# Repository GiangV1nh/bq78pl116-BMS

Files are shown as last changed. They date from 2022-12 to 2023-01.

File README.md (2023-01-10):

# Thông số kỹ thuật
- Số tế bào: 3
- Loại tế bào: Li-Ion
- Điện áp tế bào: 2.75V - 4.5V
- Điện áp pin: 8.25V - 12.6V
- Dòng nạp tối đa: 10A
- Dòng xả tối đa: 11.2A
- Cân bằng chủ động
- Dòng cân bằng: 143mA
- Giao tiếp: SMBus

Mặt trên|Mặt dưới
:-:|:-:
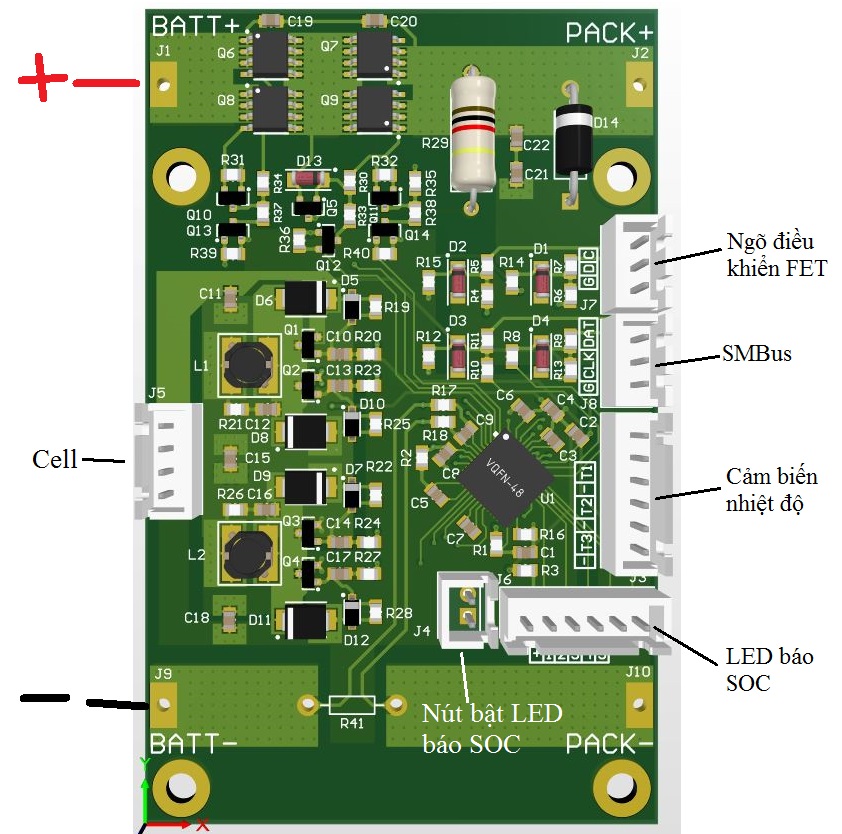
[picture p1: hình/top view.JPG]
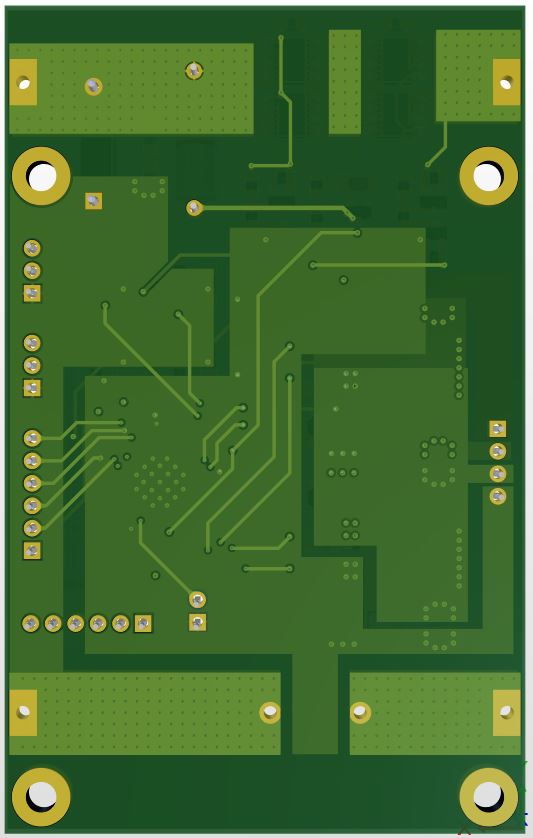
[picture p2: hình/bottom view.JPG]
|

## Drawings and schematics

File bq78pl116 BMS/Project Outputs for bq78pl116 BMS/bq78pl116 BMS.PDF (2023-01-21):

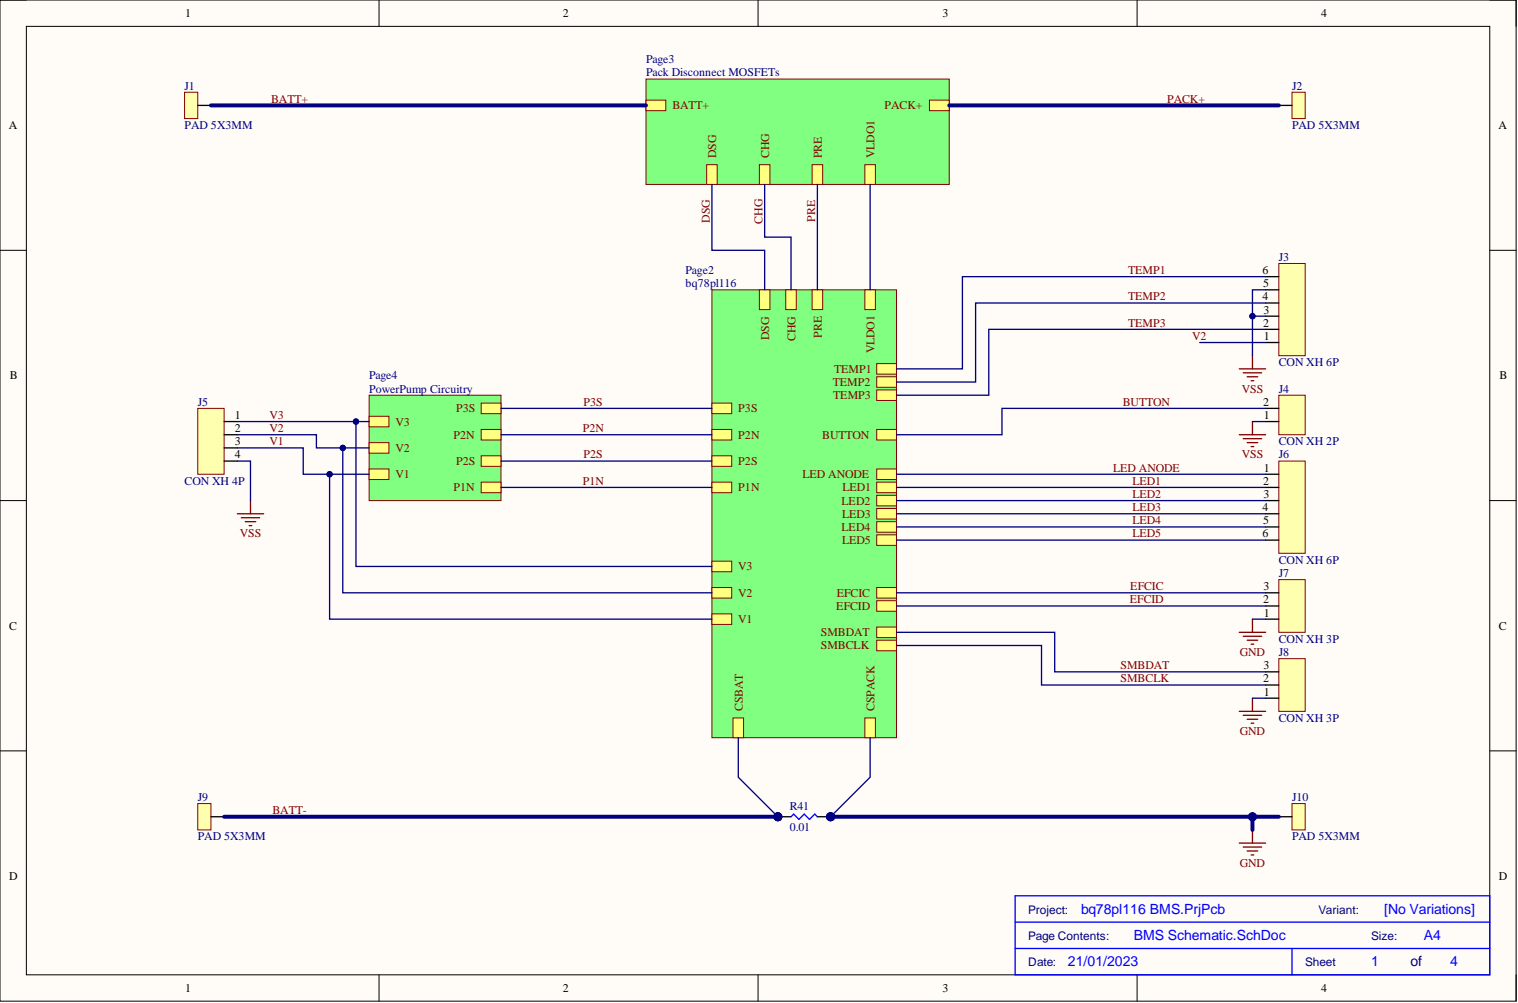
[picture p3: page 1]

T EMP3

V 2 | | P2 N
V 1

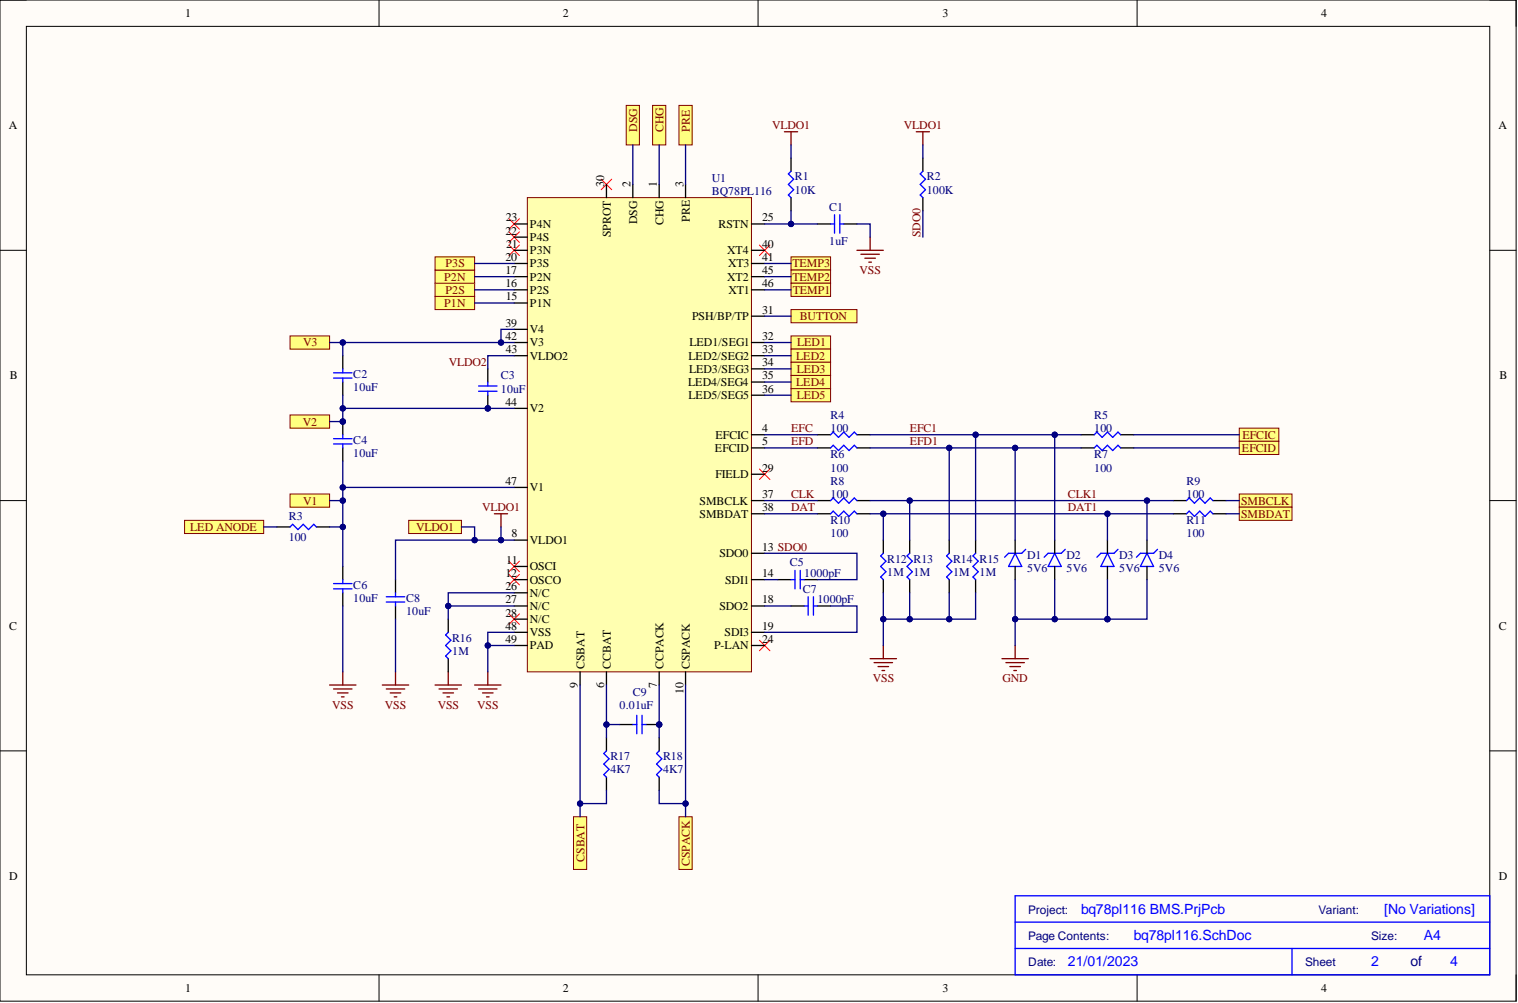
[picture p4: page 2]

P2N | TEMP2
P2S | TEMP1

OSCI 11

VSS 48

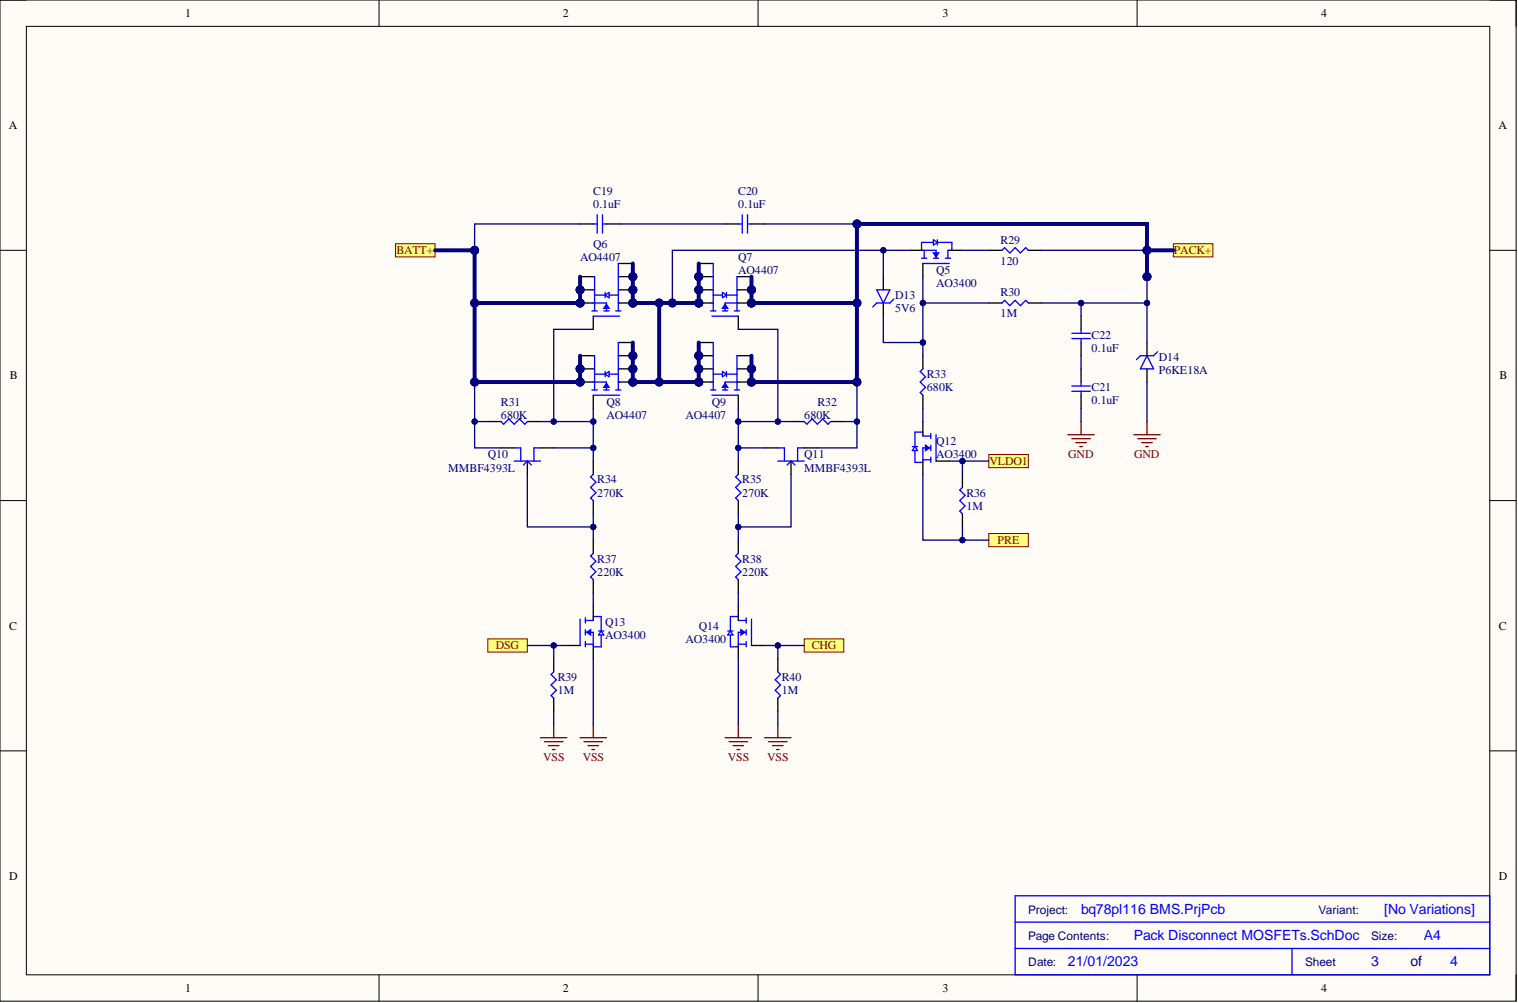
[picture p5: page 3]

D 1
5 V

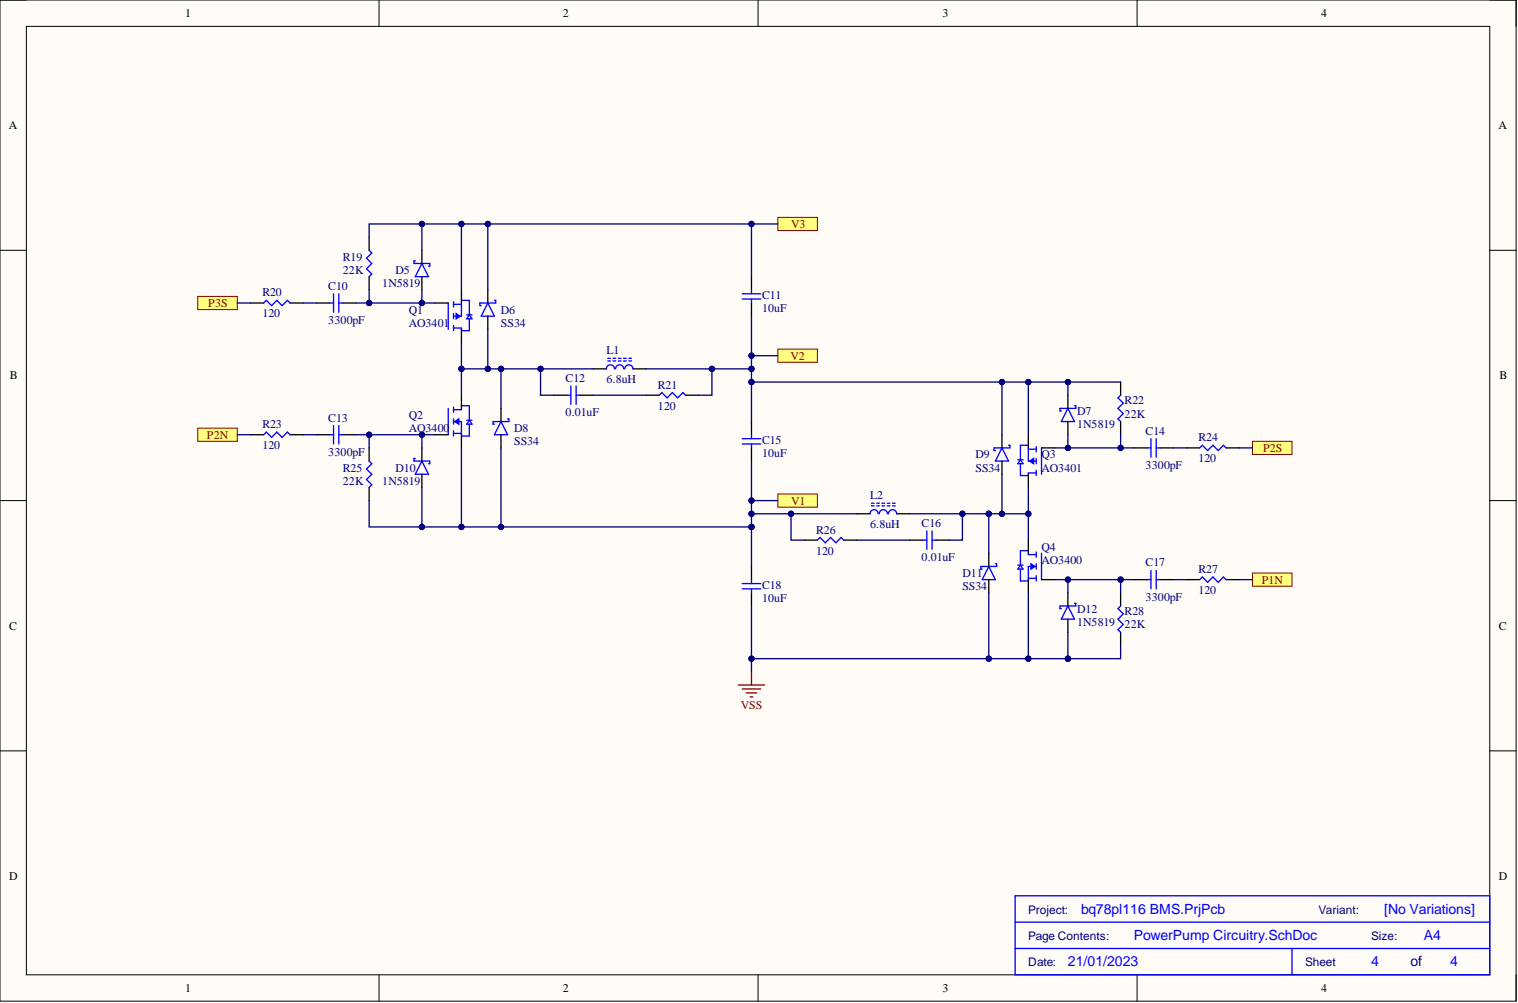
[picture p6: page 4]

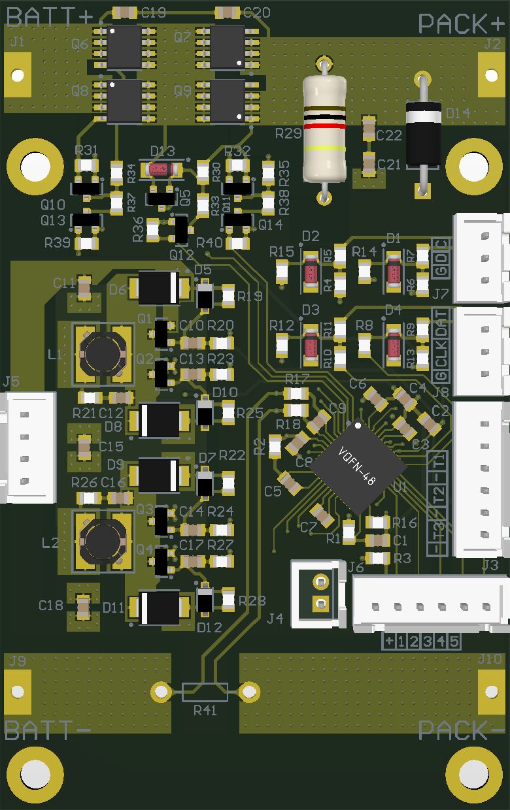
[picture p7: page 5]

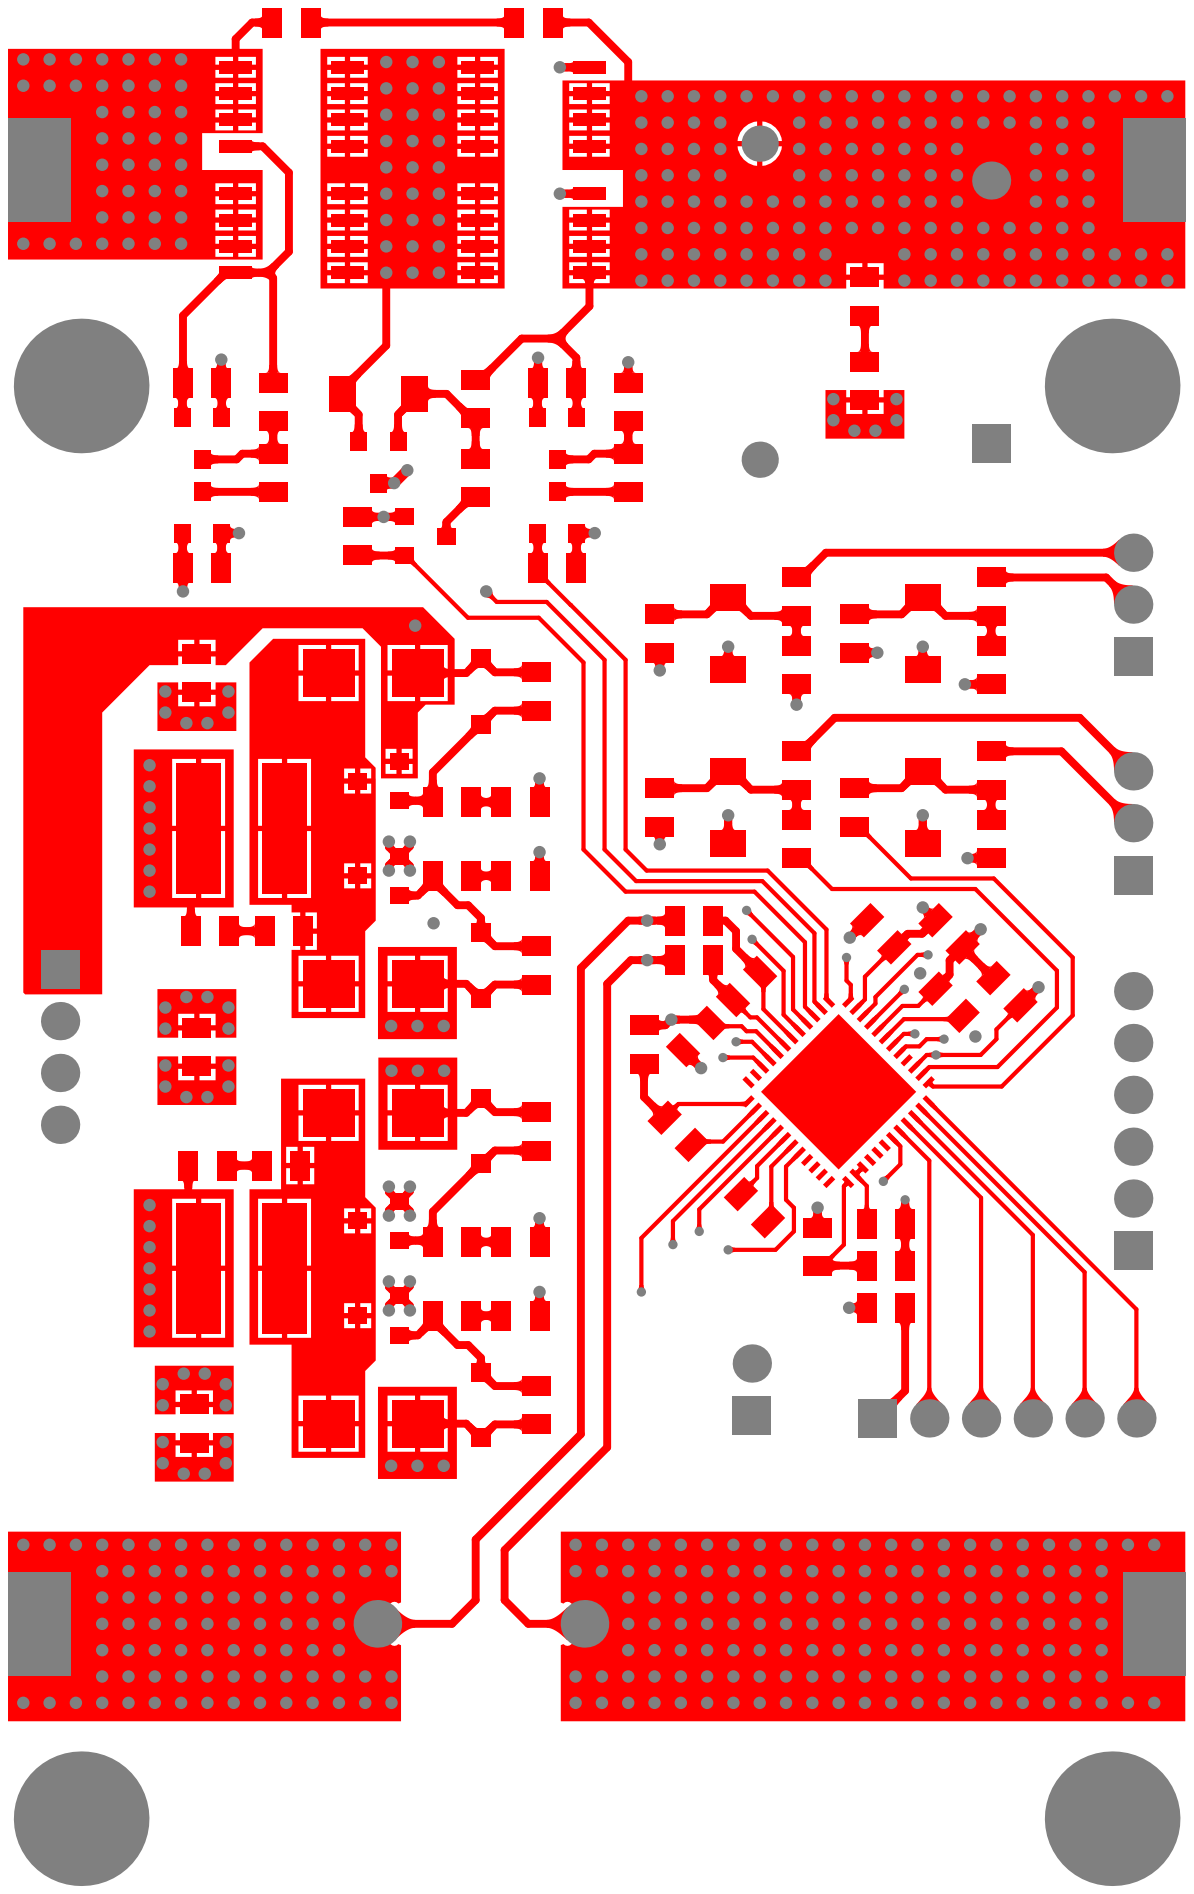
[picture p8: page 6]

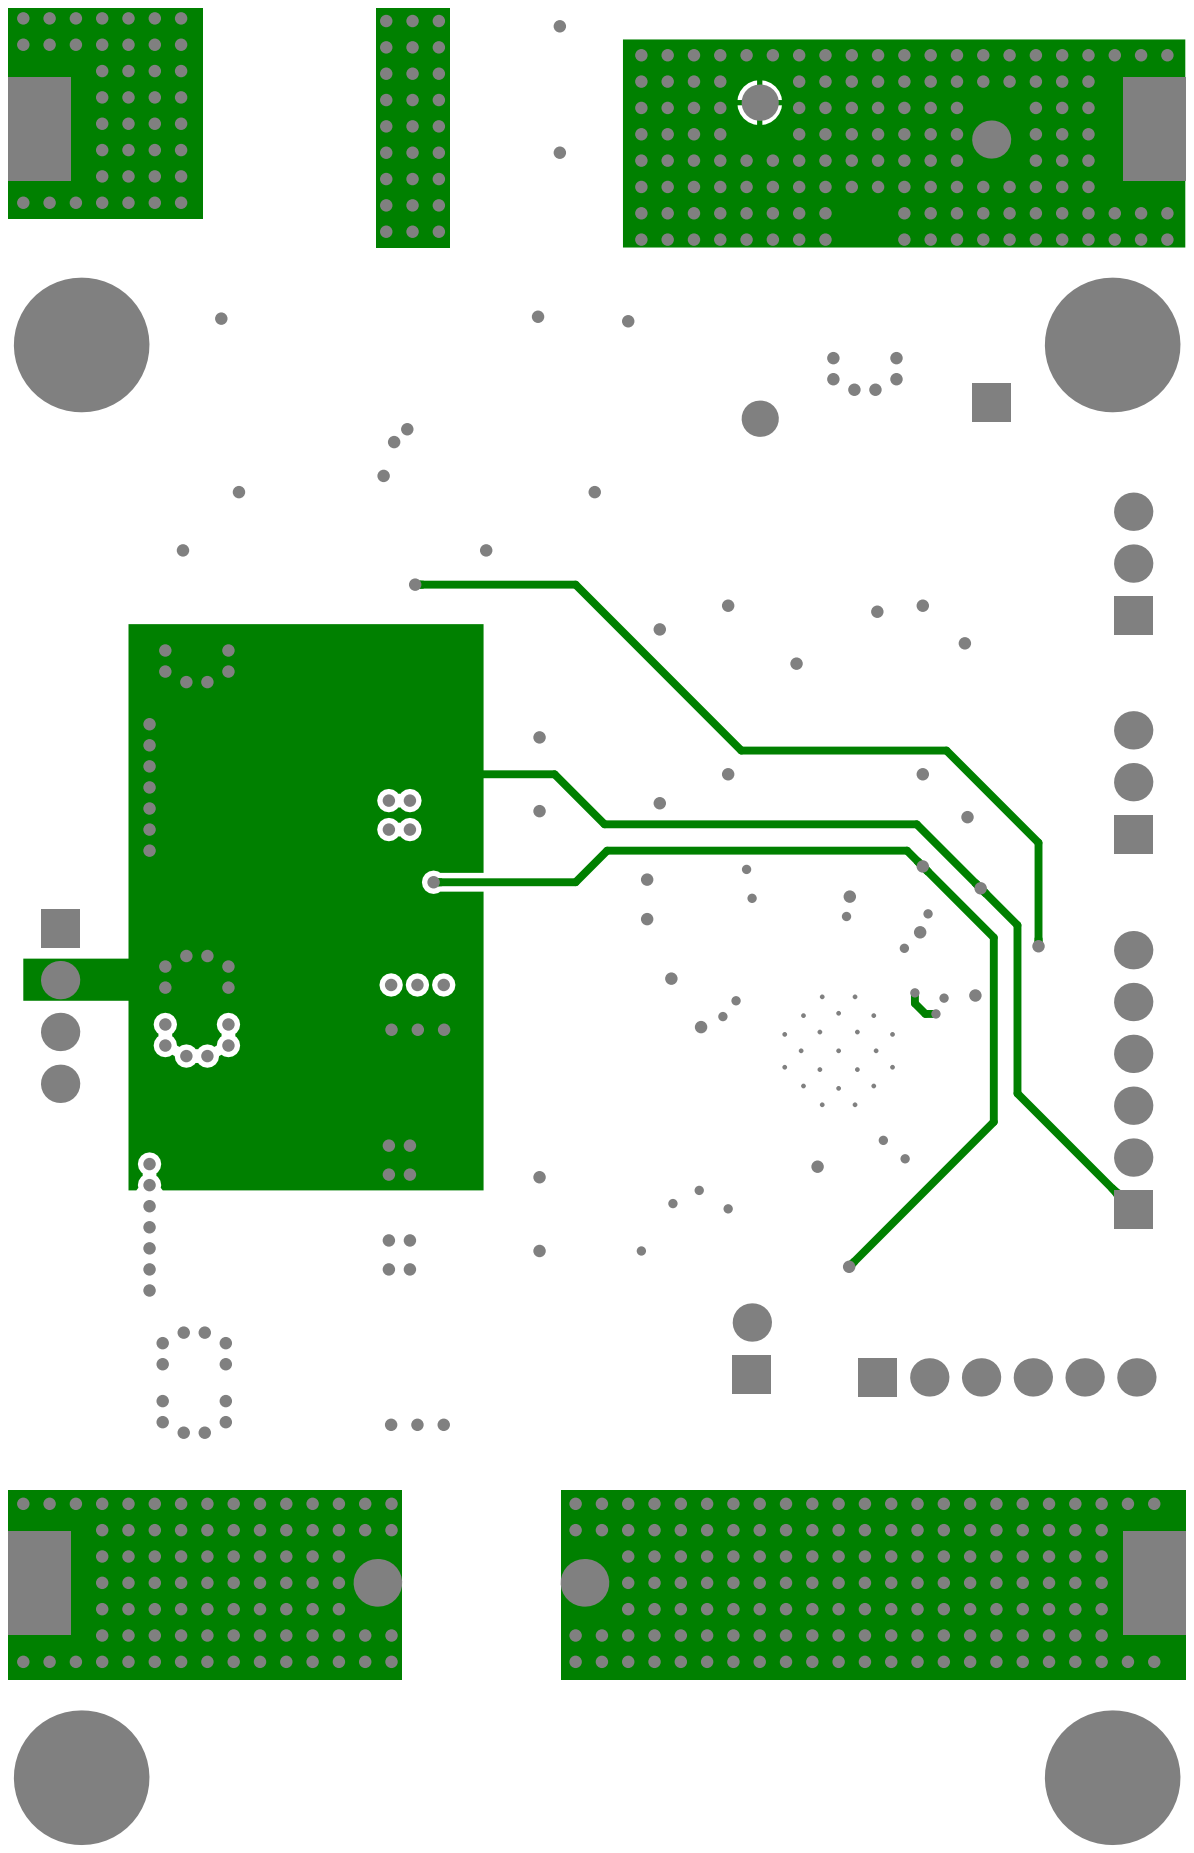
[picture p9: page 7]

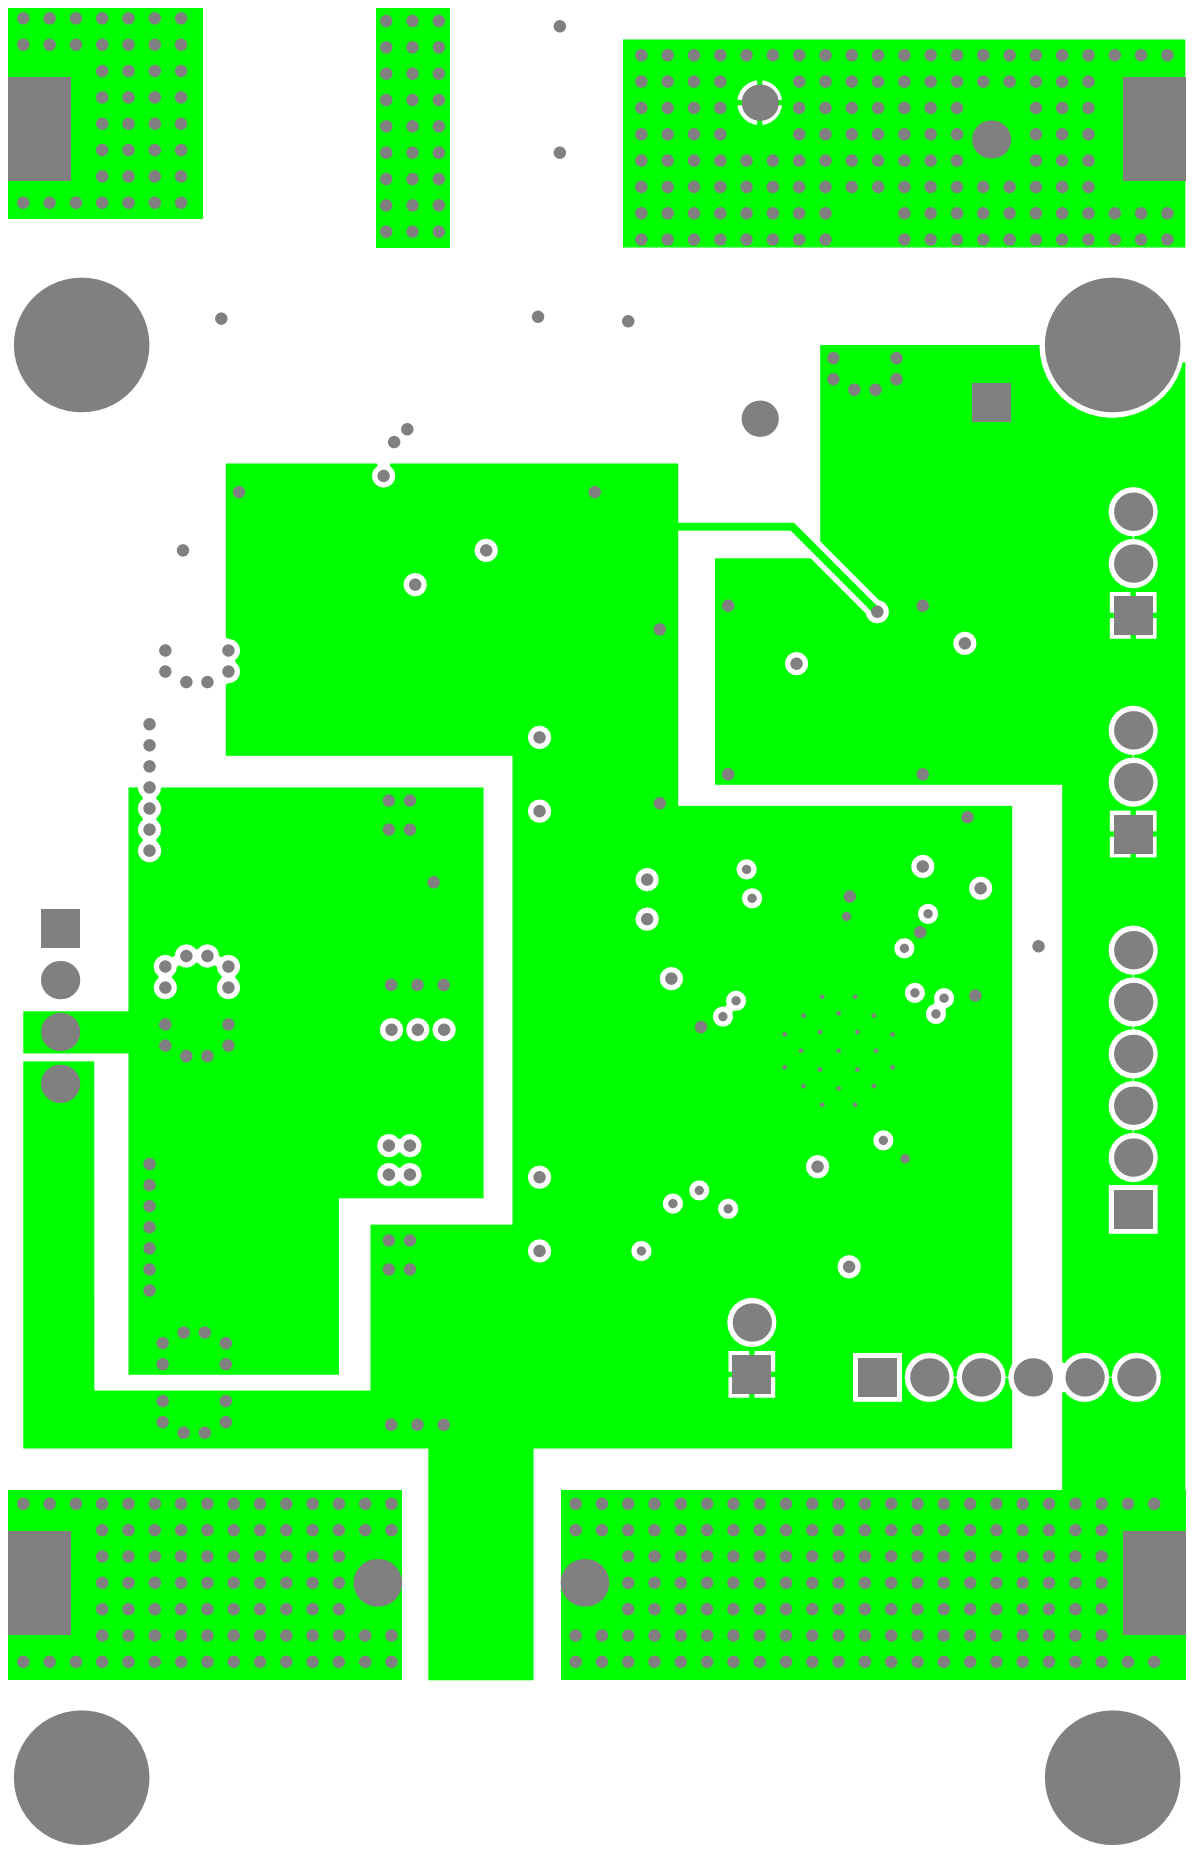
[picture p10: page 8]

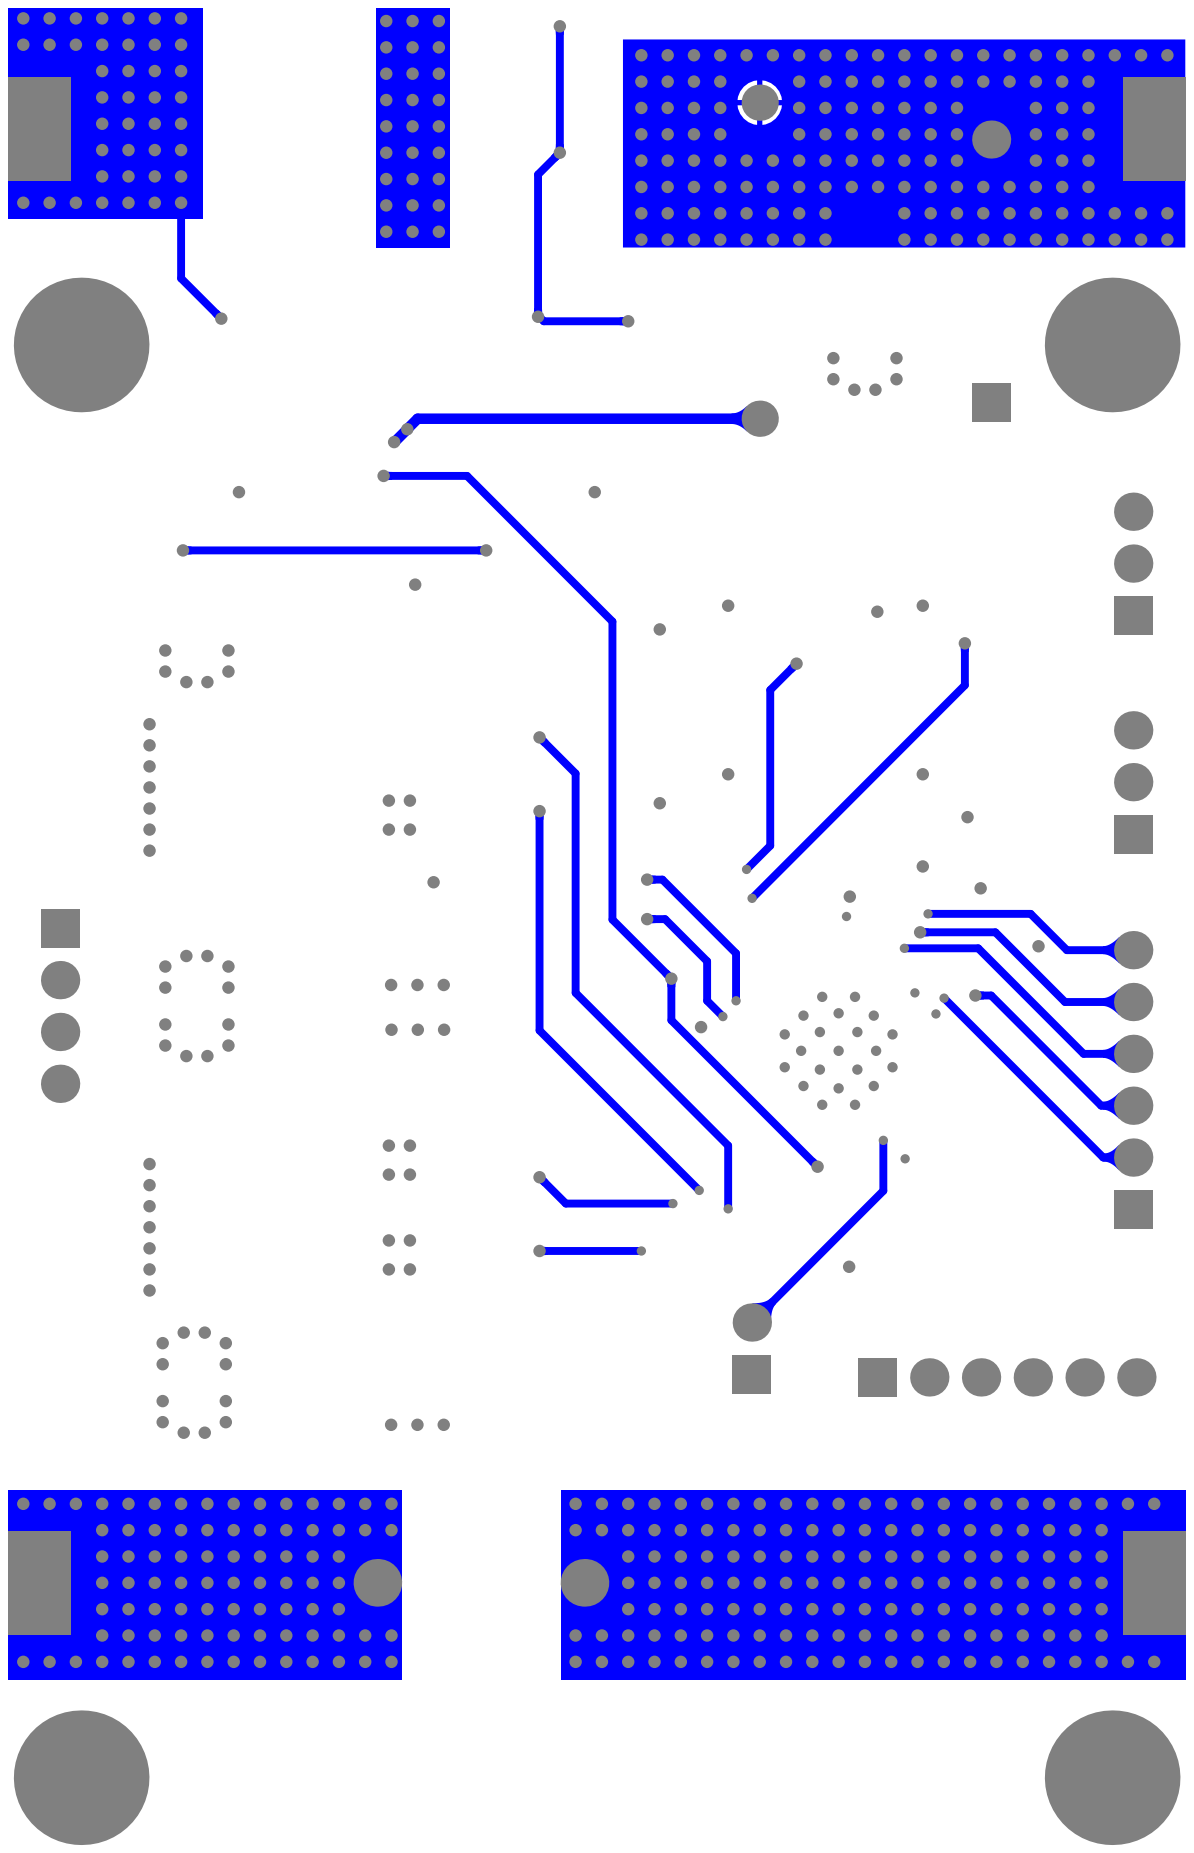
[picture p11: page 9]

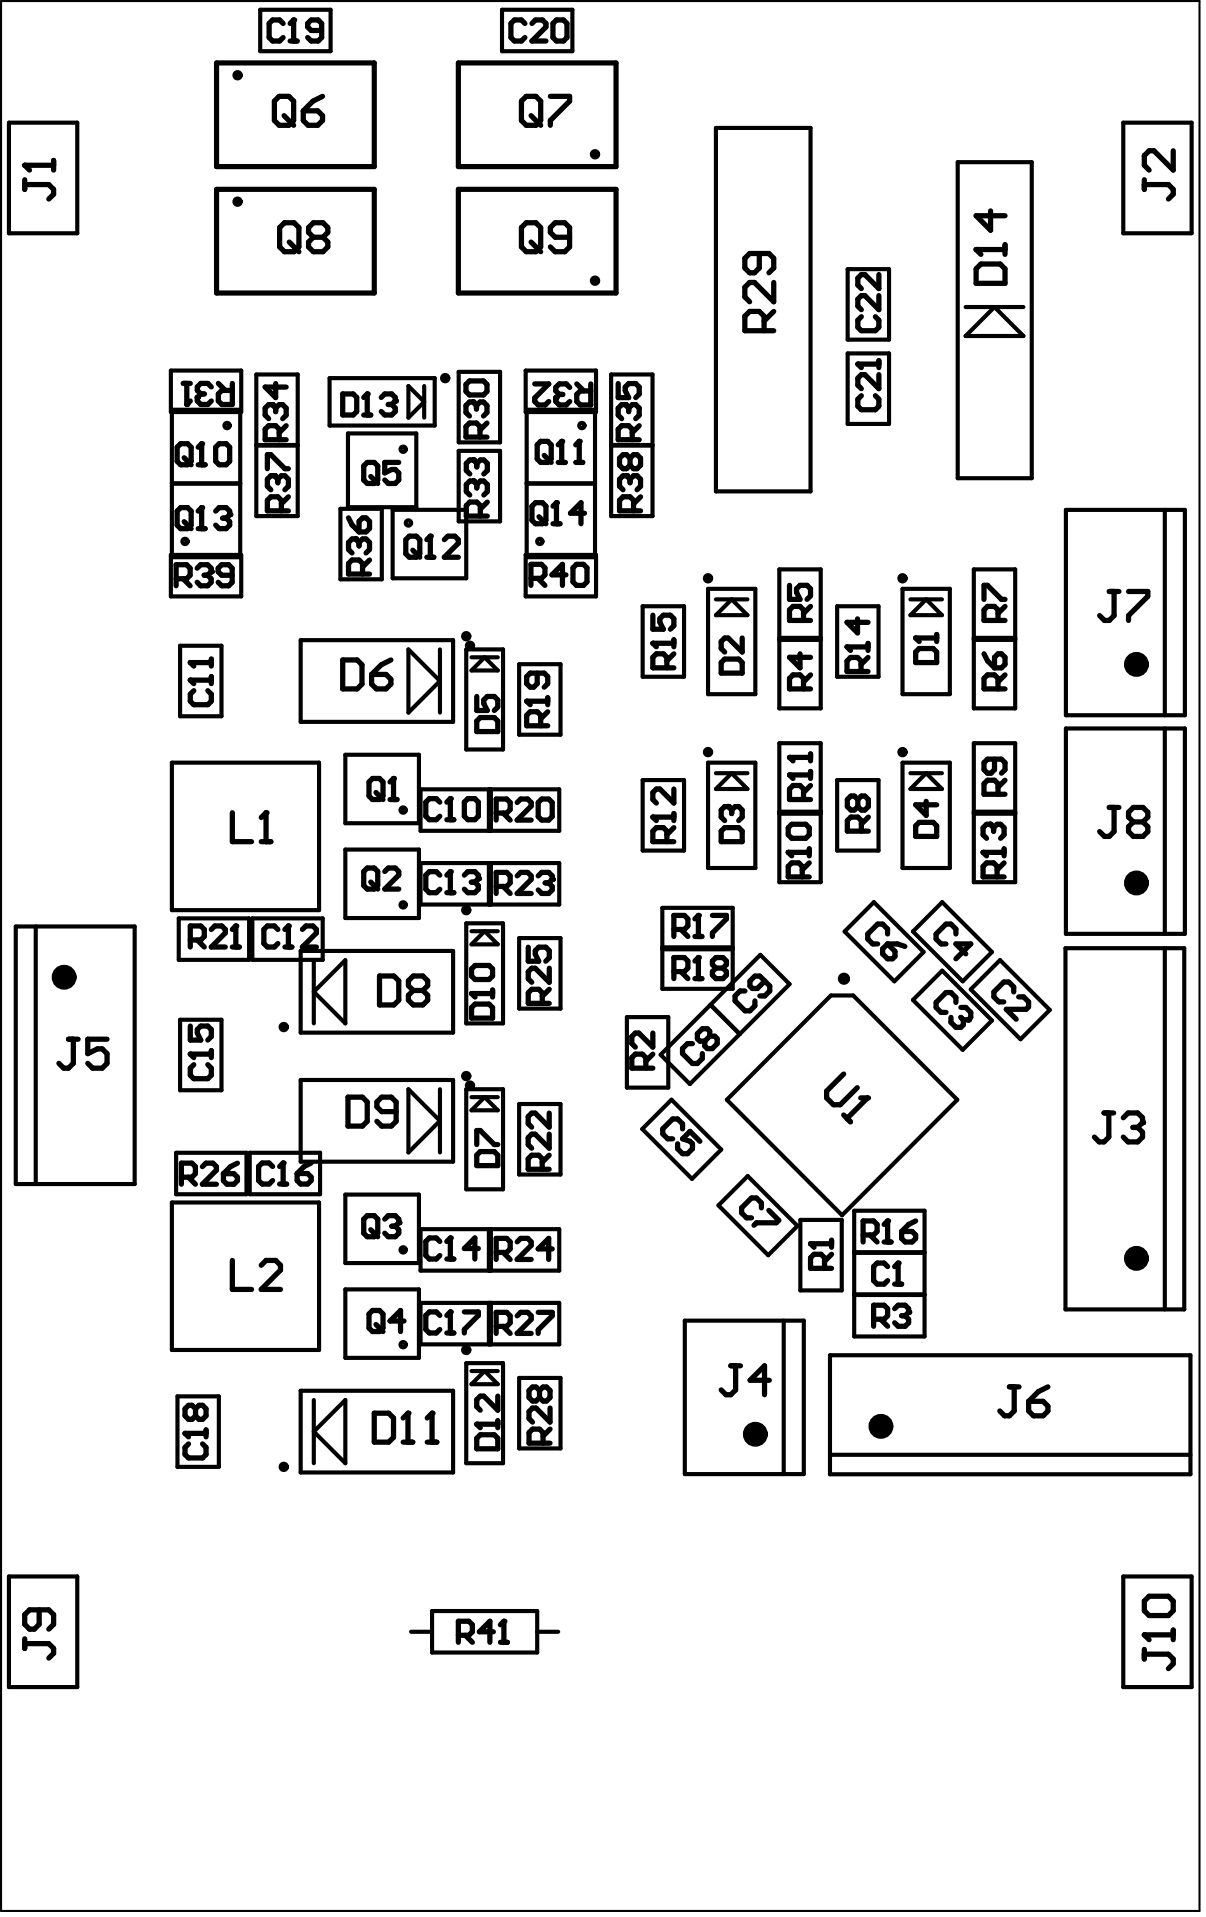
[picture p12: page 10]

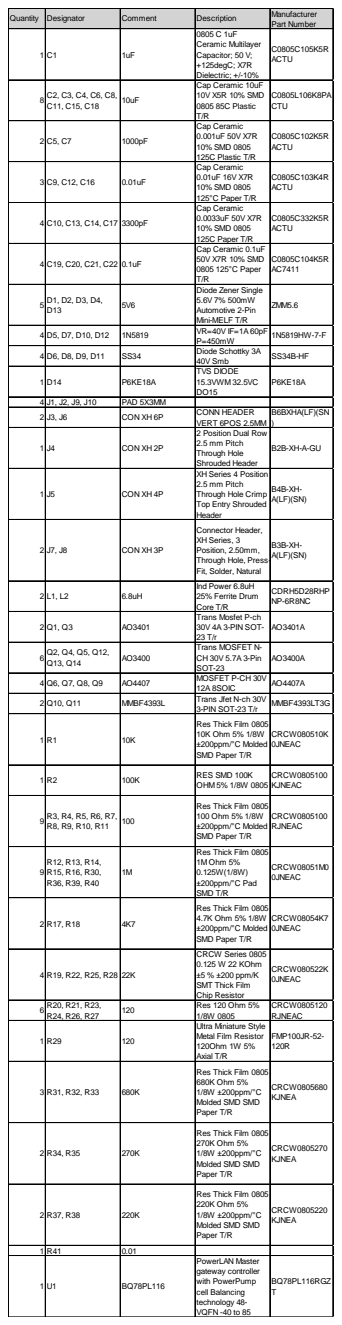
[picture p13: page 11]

Quantity | Designator | Comment | Description | Manufacturer Part Number

1 | C1 | 1uF | 0805 C 1uF Ceramic Multilayer Capacitor; 50 V; +125degC; X7R Dielectric; +/-10% | C0805C105K5R ACTU

8 | C2, C3, C4, C6, C8, C11, C15, C18 | 10uF | Cap Ceramic 10uF 10V X5R 10% SMD 0805 85C Plastic T/R | C0805L106K8PA CTU

2 | C5, C7 | 1000pF | Cap Ceramic 0.001uF 50V X7R 10% SMD 0805 125C Plastic T/R | C0805C102K5R ACTU

3 | C9, C12, C16 | 0.01uF | Cap Ceramic 0.01uF 16V X7R 10% SMD 0805 125°C Paper T/R | C0805C103K4R ACTU

4 | C10, C13, C14, C17 | 3300pF | Cap Ceramic 0.0033uF 50V X7R 10% SMD 0805 125C Paper T/R | C0805C332K5R ACTU

4 | C19, C20, C21, C22 | 0.1uF | Cap Ceramic 0.1uF 50V X7R 10% SMD 0805 125°C Paper T/R | C0805C104K5R AC7411

5 | D1, D2, D3, D4, D13 | 5V6 | Diode Zener Single 5.6V 7% 500mW Automotive 2-Pin Mini-MELF T/R | ZMM5.6

4 | D6, D8, D9, D11 | SS34 | Diode Schottky 3A 40V Smb | SS34B-HF

1 | D14 | P6KE18A | TVS DIODE 15.3VWM 32.5VC DO15 | P6KE18A

4 | J1, J2, J9, J10 | PAD 5X3MM
2 | J3, J6 | CON XH 6P | CONN HEADER VERT 6POS 2.5MM | B6BXHA(LF)(SN )

1 | J4 | CON XH 2P | 2 Position Dual Row 2.5 mm Pitch Through Hole Shrouded Header | B2B-XH-A-GU

1 | J5 | CON XH 4P | XH Series 4 Position 2.5 mm Pitch Through Hole Crimp Top Entry Shrouded Header | B4B-XH-A(LF)(SN)

2 | J7, J8 | CON XH 3P | Connector Header, XH Series, 3 Position, 2.50mm, Through Hole, Press-Fit, Solder, Natural | B3B-XH-A(LF)(SN)

2 | L1, L2 | 6.8uH | Ind Power 6.8uH 25% Ferrite Drum Core T/R | CDRH5D28RHP NP-6R8NC

2 | Q1, Q3 | AO3401 | Trans Mosfet P-ch 30V 4A 3-PIN SOT-23 T/r | AO3401A

6 | Q2, Q4, Q5, Q12, Q13, Q14 | AO3400 | Trans MOSFET N-CH 30V 5.7A 3-Pin SOT-23 | AO3400A

4 | Q6, Q7, Q8, Q9 | AO4407 | MOSFET P-CH 30V 12A 8SOIC | AO4407A

2 | Q10, Q11 | MMBF4393L | Trans Jfet N-ch 30V 3-PIN SOT-23 T/r | MMBF4393LT3G

1 | R1 | 10K | Res Thick Film 0805 10K Ohm 5% 1/8W ±200ppm/°C Molded SMD Paper T/R | CRCW080510K 0JNEAC

1 | R2 | 100K | RES SMD 100K OHM 5% 1/8W 0805 | CRCW0805100 KJNEAC

9 | R3, R4, R5, R6, R7, R8, R9, R10, R11 | 100 | Res Thick Film 0805 100 Ohm 5% 1/8W ±200ppm/°C Molded SMD Paper T/R | CRCW0805100 RJNEAC

9 | R12, R13, R14, R15, R16, R30, R36, R39, R40 | 1M | Res Thick Film 0805 1M Ohm 5% 0.125W(1/8W) ±200ppm/°C Pad SMD T/R | CRCW08051M0 0JNEAC

2 | R17, R18 | 4K7 | Res Thick Film 0805 4.7K Ohm 5% 1/8W ±200ppm/°C Molded SMD Paper T/R | CRCW08054K7 0JNEAC

4 | R19, R22, R25, R28 | 22K | CRCW Series 0805 0.125 W 22 KOhm ±5 % ±200 ppm/K SMT Thick Film Chip Resistor | CRCW080522K 0JNEAC

6 | R20, R21, R23, R24, R26, R27 | 120 | Res 120 Ohm 5% 1/8W 0805 | CRCW0805120 RJNEAC

1 | R29 | 120 | Ultra Miniature Style Metal Film Resistor 120Ohm 1W 5% Axial T/R | FMP100JR-52-120R

3 | R31, R32, R33 | 680K | Res Thick Film 0805 680K Ohm 5% 1/8W ±200ppm/°C Molded SMD SMD Paper T/R | CRCW0805680 KJNEA

2 | R34, R35 | 270K | Res Thick Film 0805 270K Ohm 5% 1/8W ±200ppm/°C Molded SMD SMD Paper T/R | CRCW0805270 KJNEA

2 | R37, R38 | 220K | Res Thick Film 0805 220K Ohm 5% 1/8W ±200ppm/°C Molded SMD SMD Paper T/R | CRCW0805220 KJNEA

1 | R41 | 0.01
1 | U1 | BQ78PL116 | PowerLAN Master gateway controller with PowerPump cell Balancing technology 48-VQFN -40 to 85 | BQ78PL116RGZ T

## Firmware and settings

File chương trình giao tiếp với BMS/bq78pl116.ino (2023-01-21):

// Chương trình này được viết để giao tiếp với BMS sử dụng IC bq78pl116 với 3 cell.
#include<Wire.h>
#define ADDRESS 0x0B
//Các hàm dùng trong chế độ SBData
void unlockSBD(void);
void writeSBD(byte, int);
int readSBD(byte);
void clearFuse(void);
void commit(void);
void relearnInitialize(void);
void enDisPowerPump(void);
void currentOffsetCalibration(void);
void currentGainCalibration(void);
void temperatureCalibration(void);
int readParameter(int);
void readVoltageSafetyParameters(void);
void readCurrentSafetyParameters(void);
void readTemperatureSafetyParameters(void);
void readSafetyParameters(void);
void readSafetyRegister(void);
void readFETStatus(bool);
void readSafetyStatus(bool);
void readPermanentDisableStatus(bool);
void readChargeStatus(bool);
void readCellStatus(bool);
void readDynamicParameters(void);
void writeSafetyParameter(void);
void readSBData(void);
void writeSBData(void);
//Các hàm dùng trong chế độ DFP
void DFPModeEnable(void);
void sendRequestDataFlashWrite(void);
void Request(unsigned int*, bool);
int Read(void);
void Write(int);
unsigned int Status(void);
void readConfigurationRegister(void);
int readDFP(unsigned int []);
void writeDFP(unsigned int [], int);
void writeConfigurationRegister(void);
void enDisSafetyRules(void);
void toggleWiredbit(void);
bool readWiredbit(void);
void exitDFP(void);
// Các hàm khác
byte CRCCalculation(byte*, byte);
void printMainMenu(void);
void printWriteSafetyParameterMenu(void);
void printWriteRegisterMenu(void);
void printEnDisSafeyRulesMenu(void);
void printEnDisPowerPumpMenu(void);
void printReadSafetyRegister(void);
void debugPEC(byte[], byte);
void printWiredbitStatus(void);
void printReadSafetyRegisterMenu(void);
int readSerial(void);
int readWord(byte);
void writeWord(byte, int);
void writeMySafetyParameters(void);
//Pack unlock
const unsigned int unlockCmd PROGMEM = 0x1A91;
//Cell overvoltage
const unsigned int COVThresold PROGMEM = 0x2400;
const unsigned int COVTime PROGMEM = 0x2300;
const unsigned int COVRecovery PROGMEM = 0x2401;
//Pack overvoltage
const unsigned int POVThresold PROGMEM = 0x2406;
const unsigned int POVTime PROGMEM = 0x2302;
const unsigned int POVRecovery PROGMEM =0x2407;
//Cell under voltage
const unsigned int CUVThresold PROGMEM = 0x2404;
const unsigned int CUVTime PROGMEM = 0x2301;
const unsigned int CUVRecovery PROGMEM = 0x2405;
//Pack undervoltage
const unsigned int PUVThresold PROGMEM = 0x2408;
const unsigned int PUVTime PROGMEM = 0x2303;
const unsigned int PUVRecovery PROGMEM = 0x2409;
//Cell extrem undervoltage
const unsigned int EUVThresold PROGMEM = 0x2416;
const unsigned int EUVTime PROGMEM = 0x230F;
const unsigned int EUVRecovery PROGMEM = 0x2417;
//OC charge tier 1
const unsigned int OCCT1Thresold PROGMEM = 0x240A;
const unsigned int OCCT1Time PROGMEM = 0x2305;
const unsigned int OCCT1Recovery PROGMEM = 0x2304;
//OC discharge tier 1
const unsigned int OCDCT1Thresold PROGMEM = 0x240B;
const unsigned int OCDCT1Time PROGMEM = 0x2307;
const unsigned int OCDCT1Recovery PROGMEM = 0x2306;
//Over current max attemps
const unsigned int OCMAttemp PROGMEM = 0x240F;
//Hardware short circuit
const unsigned int HSCThresold PROGMEM = 0x2414;
const unsigned int HSCTime PROGMEM = 0x2415;
const unsigned int HSCRecovery PROGMEM = 0x230E;
//Hardware short circuit max attemps
const unsigned int HSCMAttemp PROGMEM = 0x240E;
//Over temperature charge
const unsigned int OTCThresold PROGMEM = 0x2418;
const unsigned int OTCTime PROGMEM = 0x2310;
const unsigned int OTCRecovery PROGMEM = 0x2419;
//Charge suspend temperature high
const unsigned int CSHTemp PROGMEM = 0x2437;
const unsigned int CSHTRecovery PROGMEM = 0x2438;
//Charge inhibit temperature high
const unsigned int CIHTemp PROGMEM = 0x2430;
const unsigned int CIHTRecovery PROGMEM = 0x2431;
//Over temperature discharge
const unsigned int OTDThresold PROGMEM = 0x241A;
const unsigned int OTDTime PROGMEM = 0x2311;
const unsigned int OTDRecovery = 0x241B;
//Charge suspend temperature low
const unsigned int CSLTemp PROGMEM = 0x2435;
const unsigned int CSLTRecovery PROGMEM = 0x2436;
//Charge inhibit temperature low
const unsigned int CILTemp PROGMEM = 0x242E;
const unsigned int CILTRecovery PROGMEM = 0x242F;
//Discharge under temperature
const unsigned int DUTThresold PROGMEM = 0x2472;
const unsigned int DUTTime PROGMEM = 0x2326;
const unsigned int DUTRecovery PROGMEM = 0x2473;
//Dynamic parameters
//Lưu ý: 0x3C, 0x3D, 0x3E, 0x4B, 0x4C và 0x4D được map sang SBData bằng phần mềm bqWizard
const unsigned int V1 PROGMEM = 0x3C; // Điện áp cell 1
const unsigned int V2 PROGMEM = 0x3D; // Điện áp cell 2
const unsigned int V3 PROGMEM = 0x3E; // Điện áp cell 3
const unsigned int T1 PROGMEM = 0x4B; // Nhiệt độ cell 1
const unsigned int T2 PROGMEM = 0x4C; // Nhiệt độ cell 2
const unsigned int T3 PROGMEM = 0x4D; // Nhiệt độ cell 3
const unsigned int I PROGMEM = 0x0A; // Dòng qua pin
const unsigned int V PROGMEM = 0x09; // Điện áp pin
//Configuration registers
//Lưu ý: 
//Phần tử 0: file
//Phần tử 1: chunk
//Phần tử 2: Số chunk
const unsigned int hardwareConfiguration [3] = {0x09, 0x0048, 0x0001};
const unsigned int algorithmEnable [3] = {0x09, 0x0049, 0x0001};
const unsigned int systemControl [3] = {0x09, 0x0076, 0x0001};
//
const unsigned int requestDataFlashWrite [3] = {0x1B, 0x0000, 0x0002};
//Safety status register
//Lưu ý: Các thanh ghi này được map sang SBData bằng phần mềm bqWizard
const unsigned int FETStaus PROGMEM = 0x3F;
const unsigned int Alert0 PROGMEM = 0x40;
const unsigned int Status0 PROGMEM = 0x41;
const unsigned int Alert1 PROGMEM = 0x42;
const unsigned int Status1 PROGMEM = 0x43;
const unsigned int permanentAlert PROGMEM = 0x44;
const unsigned int permanentStatus PROGMEM = 0x45;
const unsigned int chargeAlert PROGMEM = 0x46;
const unsigned int chargeStatus PROGMEM = 0x47;
const unsigned int cell1Status PROGMEM = 0x48;
const unsigned int cell2Status PROGMEM = 0x49;
const unsigned int cell3Status PROGMEM = 0x4A;

void setup()
{
  Serial.begin(115200);
  Wire.begin();
  digitalWrite(SDA, LOW);
  digitalWrite(SCL, LOW);
  // Giới hạn tốc độ I2C ở 100KHz
  Wire.setClock(100000);
  printMainMenu();
}

void loop()
{
  static unsigned long lastMillis = 0;
  static byte mainMenuSel;
  while(Serial.available() == 0);
  mainMenuSel = readSerial();
  switch (mainMenuSel)
  {
    case 1:
      unlockSBD();
      printMainMenu();
      break;
    case 2:
      while(readSerial() == 0) // Chờ nhấn bất kỳ phím nào để thoát
      {
        if(millis() - lastMillis >= 1000) // Cập nhật một lần mỗi giây
        {
          lastMillis = millis();
          readDynamicParameters();
        }
      }
      printMainMenu();
      break;
    case 3:
      readSafetyParameters();
      printMainMenu();
      break;
    case 4:
      readSafetyRegister();
      printMainMenu();
      break;
    case 5:
      readSBData();
      printMainMenu();
      break;
    case 6:
      writeSBData();
      printMainMenu();
      break;
    case 7:
      writeSafetyParameter();
      printMainMenu();
      break;
    case 8:
      readConfigurationRegister();
      printMainMenu();
      break;
    case 9:
      writeConfigurationRegister();
      printMainMenu();
      break;
    case 10:
      toggleWiredbit();
      printMainMenu();
      break;
    case 11:
      enDisSafetyRules();
      printMainMenu();
      break;
    case 12:
      clearFuse();
      printMainMenu();
      break;
    case 13:
      relearnInitialize();
      printMainMenu();
      break;
    case 14:
      enDisPowerPump();
      printMainMenu();
      break;
    case 15:
      currentOffsetCalibration();
      printMainMenu();
      break;
    case 16:
      currentGainCalibration();
      printMainMenu();
      break;
    case 17:
      temperatureCalibration();
      printMainMenu();
      break;
    // case 18:
    //   writeMySafetyParameters();
    //   printMainMenu();
    default:
      Serial.println(F("Invalid"));
      printMainMenu();
  }
}

//Các hàm dùng trong chế độ SBData
void unlockSBD()
{
  writeSBD(0x80, unlockCmd);
}

void writeSBD(byte command, int value)
{
	writeWord(command, value);
}

int readSBD(byte command)
{
	return readWord(command);
}

void clearFuse()
{
  writeSBD(0x80, 0x200B);
}

void commit()
{
  writeSBD(0x80, 0x2003);
}

void relearnInitialize()
{
  writeSBD(0x80, 0x2007);
}

void enDisPowerPump()
{
  byte menuSel = 0;
  printEnDisPowerPumpMenu();
  while(Serial.available() == 0);
  menuSel = readSerial();
  switch (menuSel)
  {
    case 1:
      DFPModeEnable();
      writeDFP(systemControl, 0x0000);
      exitDFP();
      break;
    case 2:
      DFPModeEnable();
      writeDFP(systemControl, 0x8000);
      exitDFP();
      break;
    default:
      Serial.println(F("Invalid"));
  }
}

void currentOffsetCalibration(void)
{
  unlockSBD();
  writeSBD(0x80, 0x2000);
  Serial.println(F("Calibrating"));
  while(readSBD(0x80) != 0x0000) // Chờ IC đang trong quá trình hiệu chỉnh
  {
    delay(3);
  }
  commit();
}

void currentGainCalibration()
{
  int current = 0;
  Serial.println(F("Enter current (-32000mA to 32000mA):"));
  while(Serial.available() == 0);
  current = readSerial();
  if(current < -32000 || current > 32000)
  {
    Serial.println(F("Current out of range"));
    return;
  }
  unlockSBD();
  writeSBD(0x81, current);
  writeSBD(0x80, 0x2001);
  Serial.println(F("Calibrating"));
  while(readSBD(0x80) != 0x0000) // Chờ IC đang trong quá trình hiệu chỉnh
  {
    delay(3);
  }
  commit();
}

void temperatureCalibration()
{
  int temperature = 0;
  Serial.println(F("Enter temperature (290K to 303K):"));
  while(Serial.available() == 0);
  temperature = readSerial() * 10;
  if(temperature < 2900 || temperature > 3030)
  {
    Serial.println(F("Temperature out of range"));
    return;
  }
  unlockSBD();
  writeSBD(0x81, temperature);
  writeSBD(0x80, 0x2002);
  Serial.println(F("Calibrating"));
  while(readSBD(0X80) != 0x0000) // Chờ IC đang trong quá trình hiệu chỉnh
  {
    delay(3);
  }
  commit();
}

int readParameter(int index)
{
  writeSBD(0x80, index);
  return readSBD(0x81);
}

void readVoltageSafetyParameters()
{
  struct safetyParameters
  {
    char name [5][4] = {{"COV"}, {"POV"}, {"CUV"}, {"PUV"}, {"EUV"}};
    int thresold [5] = {readParameter(COVThresold), readParameter(POVThresold), readParameter(CUVThresold), readParameter(PUVThresold), readParameter(EUVThresold)};
    int time[5] = {readParameter(COVTime), readParameter(POVTime), readParameter(CUVTime), readParameter(PUVTime), readParameter(EUVTime)};
    int recovery[5] = {readParameter(COVRecovery), readParameter(POVRecovery), readParameter(CUVRecovery), readParameter(PUVRecovery), readParameter(EUVRecovery)};
  }voltageSafetyParameters;
  Serial.println(F("*Voltage Safety Parameters:"));
  Serial.println(F("Name\tThres\tTime\tRecov"));
  for(byte i = 0; i < 5; i++)  
  {
    Serial.print(voltageSafetyParameters.name[i]);
    Serial.print('\t');
    if(voltageSafetyParameters.thresold[i] == 0)
        Serial.print('\t');
    else
    {
      Serial.print(voltageSafetyParameters.thresold[i]);
      Serial.print('\t');
    }
    if(voltageSafetyParameters.time[i] == 0)
      Serial.print('\t');
    else
    {
      Serial.print(voltageSafetyParameters.time[i]);
      Serial.print('\t');
    }
    if(voltageSafetyParameters.recovery[i] == 0)    
      Serial.println();
    else  
      Serial.println(voltageSafetyParameters.recovery[i]);
  }
}

void readCurrentSafetyParameters()
{
  struct safetyParameters
  {
    char name [5][6] = {{"OCC"}, {"OCD"}, {"OCAt"}, {"HSC"}, {"HSCAt"}};
    int thresold [5] = {readParameter(OCCT1Thresold), readParameter(OCDCT1Thresold), readParameter(OCMAttemp), readParameter(HSCThresold), readParameter(HSCMAttemp)};
    int time [5] = {readParameter(OCCT1Time), readParameter(OCDCT1Time), 0, readParameter(HSCTime), 0};
    int recovery [5] = {readParameter(OCCT1Recovery), readParameter(OCDCT1Recovery), 0, readParameter(HSCRecovery), 0};
  }currentSafetyParameters;
  Serial.println(F("*Current Safety Parameters:"));
  Serial.println(F("Name\tThres\tTime\tRecov"));
  for(byte i = 0; i < 5; i++)  
  {
      Serial.print(currentSafetyParameters.name[i]);
      Serial.print('\t');
      if(currentSafetyParameters.thresold[i] == 0)
        Serial.print('\t');
      else
      {
        Serial.print(currentSafetyParameters.thresold[i]);
        Serial.print('\t');
      }
      if(currentSafetyParameters.time[i] == 0)
        Serial.print('\t');
      else
      {
        Serial.print(currentSafetyParameters.time[i]);
        Serial.print('\t');
      }
      if(currentSafetyParameters.recovery[i] == 0)    
        Serial.println();
      else  
        Serial.println(currentSafetyParameters.recovery[i]);
  }
}

void readTemperatureSafetyParameters()
{
  struct safetyParameters
  {
    const char name [7][5] = {{"OTC"}, {"OTD"}, {"CIHT"}, {"CILT"}, {"CSHT"}, {"CSLT"}, {"DUT"}};
    int thresold [7] = {readParameter(OTCThresold), readParameter(OTDThresold), readParameter(CIHTemp), readParameter(CILTemp), readParameter(CSHTemp), readParameter(CSLTemp), readParameter(DUTThresold)};
    int time [7] = {readParameter(OTCTime), readParameter(OTCTime), 0, 0, 0, 0, readParameter(DUTTime)};
    int recovery [7] = {readParameter(OTCRecovery), readParameter(OTDRecovery), readParameter(CIHTRecovery), readParameter(CILTRecovery), readParameter(CSHTRecovery), readParameter(CSLTRecovery), readParameter(DUTRecovery)};  
  }temperatureSafetyParameters;
  Serial.println(F("*Temperature Safety Parameters:"));
  Serial.println(F("Name\tThres\tTime\tRecov"));
  for(byte i = 0; i < 7; i++)  
  {
    Serial.print(temperatureSafetyParameters.name[i]);
    Serial.print('\t');
    if(temperatureSafetyParameters.thresold[i] == 0)
        Serial.print('\t');
    else
    {
      Serial.print(temperatureSafetyParameters.thresold[i]);
      Serial.print('\t');
    }
    if(temperatureSafetyParameters.time[i] == 0)
      Serial.print('\t');
    else
    {
      Serial.print(temperatureSafetyParameters.time[i]);
      Serial.print('\t');
    }
    if(temperatureSafetyParameters.recovery[i] == 0)    
      Serial.println();
    else  
      Serial.println(temperatureSafetyParameters.recovery[i]);
  }
}

void readSafetyParameters()
{
  Serial.println(F("|**********Safety parameters*********|"));
  unlockSBD();
  readVoltageSafetyParameters();
  readCurrentSafetyParameters();
  readTemperatureSafetyParameters();
}

void readSafetyRegister()
{
  byte menuSel = 0;
  printReadSafetyRegisterMenu();
  while(Serial.available() == 0);
  menuSel = readSerial();
  switch (menuSel)
  {
    case 1: 
      readFETStatus(false);
      break;
    case 2:
      readSafetyStatus(false);
      break;
    case 3:
      readPermanentDisableStatus(false);
      break;
    case 4:
      readChargeStatus(false);
      break;
    case 5:
      readCellStatus(false);
      break;
    default:
      Serial.println(F("Invalid"));
  }
}

void readFETStatus(bool printSetbit)
{
  unsigned int FETStatusRegister = readSBD(FETStaus);
	const char FETStatusBitName [3][5] = {{"DFET"},
							                          {"CFET"},
							                          {"PFET"}};
  Serial.println(F("*FET Status:"));
  if(printSetbit == false || (printSetbit == true && (FETStatusRegister & 0x0007) != 0x0007))
	{
    Serial.println(F("Name\tStatus"));
    for(unsigned int i = 0, n = 1; i < 3; i++, n<<=1)
    {
      if(printSetbit == false || (printSetbit == true && ((FETStatusRegister & n) == 0)))
      {
        Serial.print(FETStatusBitName[i]);
        Serial.print('\t');
        (FETStatusRegister & n) != 0? Serial.println(true) : Serial.println(false);
      }
    }
  }
}

void readSafetyStatus(bool printSetbit)
{
  unsigned int safetyAlertRegister = readSBD(Alert0);
  unsigned int safetyStatusRegister = readSBD(Status0);
  unsigned int safetyAlert1Register = readSBD(Alert1);
  unsigned int safetyStatus1Register = readSBD(Status1);
  const char safetyStatusAlertBitname [17][5] = {{"HOCD"}, {"HOCC"}, {"HSC"}, {"EUV"}, {"HWDG"}, {"COV"}, {"BOT"}, {"CUV"},
                                                  {"POV"}, {"PUV"}, {"OCC2"}, {"OCD2"}, {"OCC"}, {"OCD"}, {"OTC"}, {"OTD"},
                                                  {"DUT"}};
  Serial.println(F("*Safety status:"));
  if(printSetbit == false || (printSetbit == true && (((safetyAlertRegister & 0xFFFF) != 0 || (safetyStatusRegister & 0xFFFF) != 0 || (safetyAlert1Register & 0x0002) != 0) || (safetyStatus1Register & 0x0002) != 0)))
  {
    Serial.println(F("Name\tAlert\tStatus"));
    for(unsigned int i = 0, n = 1; i < 16; i++, n<<=1)
    {
      if(printSetbit == false || (printSetbit == true && ((safetyAlertRegister & n) != 0 || (safetyStatusRegister & n) != 0)))
      {
        Serial.print(safetyStatusAlertBitname[i]);
        Serial.print('\t');
        (safetyAlertRegister & n) != 0 ? Serial.print(true) : Serial.print(false);
        Serial.print('\t');
        (safetyStatusRegister & n) != 0 ? Serial.println(true) : Serial.println(false);
      }
    }
    if(printSetbit == false || (printSetbit == true && ((safetyAlert1Register & 0x0002) != 0 || (safetyStatus1Register & 0x0002) != 0)))
    {
      Serial.print(safetyStatusAlertBitname[16]);
      Serial.print('\t');
      (safetyAlert1Register & 0x0002) != 0 ? Serial.print(true) : Serial.print(false);
      Serial.print('\t');
      (safetyStatus1Register & 0x0002) != 0 ? Serial.println(true) : Serial.println(false);
    }
  }
}

void readPermanentDisableStatus(bool printSetbit)
{
  unsigned int permanentDisableAlertRegister = readSBD(permanentAlert);
  unsigned int permanentDisableStatusRegister = readSBD(permanentStatus);
  const char permanentDisableAlertStatusBitName [15][6] = {{"SOV"}, {"SOTC"}, {"SOTD"}, {"CIM"}, {"CFETF"}, {"DFETF"}, {"OTS"}, {"CMF"},
                                                            {"VLAN"}, {"SOCC"}, {"SOCD"}, {"ROR"}, {"IGRR"}, {"IGR"}, {"FBF"}};
  Serial.println(F("*Permanent disable status:"));
  if(printSetbit == false || (printSetbit == true && ((permanentDisableAlertRegister & 0xFFFE) != 0 || (permanentDisableStatusRegister & 0xFFFE) != 0)))
  {
    Serial.println(F("Name\tAlert\tStatus"));
    for(unsigned int i = 0, n = 2; i < 15; i++, n<<=1)
    {
      if(printSetbit == false || (printSetbit == true && ((permanentDisableAlertRegister & n) != 0 || (permanentDisableStatusRegister & n) != 0)))
      {
        Serial.print(permanentDisableAlertStatusBitName[i]);
        Serial.print('\t');
        (permanentDisableAlertRegister & n) != 0 ? Serial.print(true) : Serial.print(false);
        Serial.print('\t');
        (permanentDisableStatusRegister & n) != 0 ? Serial.println(true) : Serial.println(false);
      }
    }
  }
}

void readChargeStatus(bool printSetbit)
{
  unsigned int chargeAlertRegister = readSBD(chargeAlert);
  unsigned int chargeStatusRegister = readSBD(chargeStatus);
  const char chargeAlertStatusBitname [10][5] = {{"CSLT"}, {"CSHT"}, {"CILT"}, {"CIHT"}, {"PV"}, {"PT"}, {"CT"}, {"PTO"},
                                                  {"CC"}, {"DC"}};
  Serial.println(F("*Charge status:"));
  if(printSetbit == false || (printSetbit == true && ((chargeAlertRegister & 0xFFC0) != 0 || (chargeStatusRegister & 0xFFC0) != 0)))
  {
    Serial.println(F("Name\tAlert\tStatus"));
    for(unsigned int i = 0, n = 64; i < 10; i++, n<<=1)
    {
      if(printSetbit == false || (printSetbit == true && ((chargeAlertRegister & n) != 0 || (chargeStatusRegister & n) != 0)))
      {
        Serial.print(chargeAlertStatusBitname[i]);
        Serial.print('\t');
        (chargeAlertRegister & n) != 0 ? Serial.print(true) : Serial.print(false);
        Serial.print('\t');
        (chargeStatusRegister & n) != 0 ? Serial.println(true) : Serial.println(false);
      }
    }
  }
}

void readCellStatus(bool printSetbit)
{
  unsigned int cell1StatusRegister = readSBD(cell1Status);
  unsigned int cell2StatusRegister = readSBD(cell2Status);
  unsigned int cell3StatusRegister = readSBD(cell3Status);
  const char cellStatusBitName [6][6] = {{"North"}, {"South"}, {"OV"}, {"UV"}, {"OT"}, {"UT"}};
  Serial.println(F("*Cell status:"));
  if(printSetbit == false || (printSetbit == true && ((cell1StatusRegister & 0x003F) != 0 || (cell2StatusRegister & 0x003F) != 0 || (cell3StatusRegister & 0x003F) != 0)))
  {
    Serial.println(F("Name\tCell1\tCell2\tCell3"));
    for(unsigned int i = 0, n = 1; i < 6; i++, n<<=1)
    {
      if(printSetbit == false || (printSetbit == true && ((cell1StatusRegister & n) != 0 || (cell2StatusRegister & n) != 0 || (cell3StatusRegister & n) != 0)))
      {
        Serial.print(cellStatusBitName[i]);
        Serial.print('\t');
        (cell1StatusRegister & n) != 0 ? Serial.print(true) : Serial.print(false);
        Serial.print('\t');
        (cell2StatusRegister & n) != 0 ? Serial.print(true) : Serial.print(false);
        Serial.print('\t');
        (cell3StatusRegister & n) != 0 ? Serial.println(true) : Serial.println(false);
      }
    }
  }
}

void readDynamicParameters()
{
  int DynamicParameters [8] = {readSBD(V1), readSBD(V2), readSBD(V3),
                                (readSBD(T1) / 10) - 272, (readSBD(T2) / 10) -272 , (readSBD(T3) / 10) - 272,
                                readSBD(V), readSBD(I)};
  Serial.println(F("|*********Dynamic parameters*********|"));
  for(byte i = 0; i < sizeof(DynamicParameters) / 2; i++)
  {
    if(i == 0)
      Serial.println(F("V1\tV2\t\V3"));
    else if(i == 3)
      Serial.println(F("T1\tT2\t\T3"));
    else if(i == 6)
      Serial.println(F("V\tI"));
    Serial.print(DynamicParameters[i]);
    if(i == 2 || i == 5 || i == 7)
      Serial.println();
    else
      Serial.print('\t');
  }
  readFETStatus(true);
  readSafetyStatus(true);
  readPermanentDisableStatus(true);
  readChargeStatus(true);
  readCellStatus(true);
}
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

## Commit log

2022-12-26 Tải lên file mạch
    [BMS PCB.PcbDoc, BMS Schematic.SchDoc, Pack Disconnect MOSFETs.SchDoc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]
2022-12-26 cập nhật readme
2022-12-26 cập nhật hình mạch in
2022-12-26 cập nhật top view
2023-01-13 Chương trình giao tiếp với BMS
2023-01-21 Cập nhật BMS PCB.PcbDoc
    [BMS PCB.PcbDoc]
2023-01-21 Cập nhật file gerber
    [BMS PCB.GBL, BMS PCB.GBO, BMS PCB.GBP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]
2023-01-21 Cập nhật file NC Drill
2023-01-21 Rename bq78pl116.ino to chương trình giao tiếp với BMS/bq78pl116.ino
